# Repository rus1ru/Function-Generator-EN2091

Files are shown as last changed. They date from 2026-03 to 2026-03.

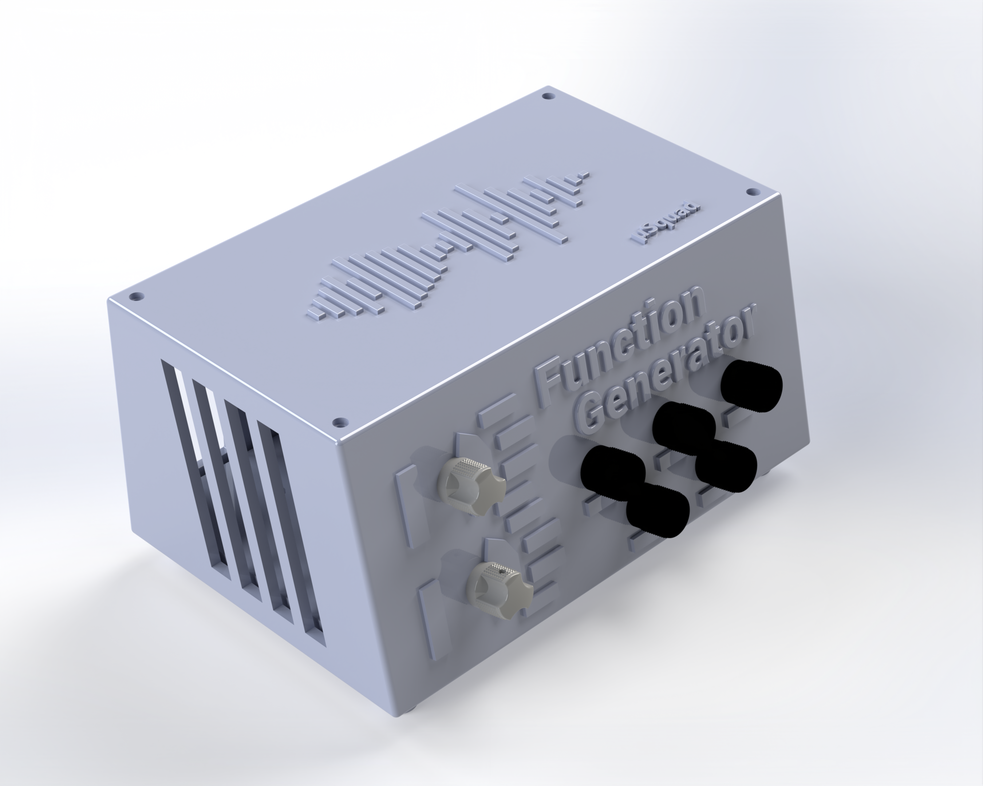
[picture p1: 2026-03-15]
CAD_Files/Vizualize files/isometric view.png

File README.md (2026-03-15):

# Function Generator (EN2091)

Hardware design repository for an analog function generator project, including PCB design sources, mechanical enclosure files, and project documentation.

## Project Overview

This repository contains the design artifacts for the EN2091 Function Generator project:

- Electronic design files (schematic and PCB layout)
- Mechanical enclosure and assembly CAD files
- Exported 3D models for integration and viewing
- Supporting documentation (datasheet, user manual, presentation)

Notes:
- The folder name Enclosuer Design Files is kept as-is to match the existing project structure.
- File naming is preserved from original design exports.

## Design Assets

### 1) PCB Design

Located in PCB Files:

- schematic_Func_Gen.SchDoc: Altium schematic source
- PCB_Func_Gen.PcbDoc: Altium PCB layout source

Use these files for circuit review, design updates, ERC/DRC checks, and fabrication export generation (Gerbers, drill files, BOM, pick-and-place).

### 2) Mechanical and Enclosure Design

Located in Enclosuer Design Files:

- Assembly New.SLDASM: Main SolidWorks assembly
- Box new.SLDPRT: Enclosure body part
- Box New Lid.SLDPRT: Enclosure lid part
- pcba.step: STEP export of the board assembly for mechanical fit checks
- knobs-15.snapshot.5/*.step: Knob variants as STEP files for integration

Use these files for enclosure modification, tolerance/fit validation, and 3D visualization.

### 3) Documentation

- Analog Function Generator Datasheet.pdf
- Analog Function Generator User Manual.pdf
- Analog Function Generator Presentation.pdf

These documents describe project intent, operation, and presentation material.

## Recommended Software

To work with the source files:

- Altium Designer (for .SchDoc and .PcbDoc)
- SolidWorks (for .SLDASM and .SLDPRT)
- Any CAD viewer with STEP support (for .step)
- PDF reader (for project documents)

## Getting Started

1. Clone the repository.
2. Open PCB Files/schematic_Func_Gen.SchDoc and PCB Files/PCB_Func_Gen.PcbDoc in Altium Designer.
3. Open Enclosuer Design Files/Assembly New.SLDASM in SolidWorks.
4. Verify PCB-to-enclosure fit using Enclosuer Design Files/pcba.step.
5. Review the Datasheet and User Manual before making design changes.

## License

This project is licensed under the MIT License.
See the LICENSE file for details.

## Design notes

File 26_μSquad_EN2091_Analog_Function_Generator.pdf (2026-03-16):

## University of Moratuwa

Faculty of Engineering

Department of Electronic and Telecommunication Engineering

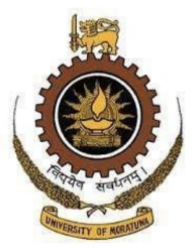
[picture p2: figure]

EN2091 – Laboratory Practice and Projects

Final Report

## Analog Function Generator

Group Members

230436X Nettikumara N.A.H.G. 230436E Rasanjana W.P.G.R.A 230180F Fernando H.M.D.
230322U Karunarathne G.K.T.

Date: 14.12.2025

Abstract

This report presents the design and implementation of an analog function generator capable of producing sine, square, triangular, and sawtooth waveforms. The system was constructed entirely using analog components such as operational amplifiers, transistors, resistors, capacitors, and MOSFETs. The function generator provides adjustable amplitude from 0 V to 10 V, frequency variation from 20 Hz to 20 kHz, and a variable duty cycle for PWM signals ranging from 1% to 99%. Design methodologies, circuit calculations, component selection, PCB layout, enclosure design, and experimental validation are discussed in detail. Simulation and hardware testing confirm that the generator meets the required specifications while maintaining signal integrity.

## Contents

1 Introduction and Functionality | 1
2 Requirements | 1
3 Calculations and Design | 2
4 Selection of Components | 6
5 Power Supply | 6
6 Push-Pull Output with Voltage Buffer, DC shifter and inverting amplifier | 7
7 Simulation and Testing | 8
8 PCB Design | 9
9 Enclosure Design | 11

10 Final Product Results | 13
11 Future Improvements | 14
12 Contribution of Group Members | 14
13 References | 15

## 1 Introduction and Functionality

A function generator is a fundamental laboratory instrument used for testing, debugging, and characterizing electronic systems. It provides periodic waveforms of selectable shape, frequency, and amplitude. In this project, an analog function generator was designed using discrete and integrated analog components, without employing any digital signal generation techniques.

The proposed system is capable of generating square, triangular, sawtooth, and PWM waveforms using a closed-loop configuration consisting of a Schmitt trigger and an integrator. The Schmitt trigger generates a square wave, which is subsequently integrated to obtain triangular and sawtooth waveforms. PWM generation is achieved by appropriate adjustment of the comparator thresholds within the same loop.

For sine wave generation, a Wien bridge oscillator topology was employed due to its low distortion and stable frequency characteristics. All signal-generation and conditioning stages were implemented using TL072CP operational amplifiers, selected for their high slew rate and sufficient bandwidth to support operation across the full frequency range.

The function generator operates over a frequency range of 20 Hz to 20 kHz. Frequency control is achieved using RC-based timing networks, where different frequency bands are selected by switching timing capacitors, and continuous frequency variation within each band is provided by a potentiometer. Amplitude variation and DC offset control are implemented using summing and buffer amplifier stages, enabling flexible output conditioning.

A push-pull output stage ensures sufficient current-drive capability for low-impedance loads. In addition, a dedicated dual-polarity power supply (±12 V) was designed and implemented to meet the operational requirements of the analog circuitry and to ensure stable, symmetric signal swing.

## 2 Requirements

The design meets the following specifications:

- Output waveforms: Sine, Square, Triangle, Sawtooth
- Frequency range: 20 Hz to 20 kHz
- Amplitude variation: 0 V to 10 V
- PWM duty cycle range: 1% to 99%
- Minimum load driving capability: 50 Ω

## 3 Calculations and Design

### 3.1 Square Wave Generation

A Schmitt trigger configuration using an operational amplifier was employed for square wave generation. Positive feedback introduces hysteresis, allowing the circuit to switch states when the input crosses defined threshold levels.

VT H = ±

R8
R8 + R9
Vsat | (1)

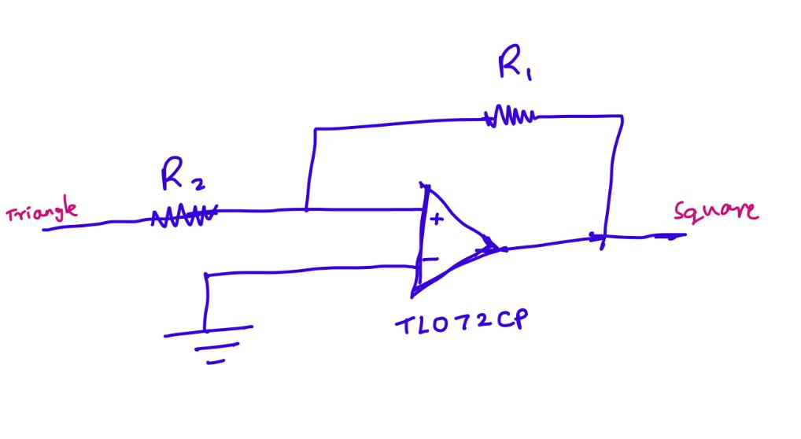
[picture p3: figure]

Figure 1: Schmitt trigger based square wave generator

### 3.2 PWM Wave Generation

Pulse Width Modulation (PWM) is obtained by applying a controllable DC bias to the non-inverting terminal of the integrator. The bias voltage is varied between −Vs (−12 V) and +Vs (+12 V) using the potentiometer R11 connected across the dual supply rails.

A triangular waveform, generated by integrating the square wave output of the Schmitt trigger, is compared against this adjustable reference level. Varying the DC offset shifts the triangular waveform relative to the switching thresholds, thereby altering the switching instants of the output. This results in a PWM waveform whose duty cycle varies continuously while maintaining a constant frequency. Consequently, the average output voltage of the PWM signal can be precisely controlled.

### 3.3 Sawtooth Wave Generation

The sawtooth waveform is generated by introducing a DC offset to the integrator using the potentiometer R11. The applied DC bias causes the charging and discharging slopes of the integrator capacitor to become unequal.

As a result, the capacitor charges slowly in one direction and discharges more rapidly in the opposite direction, transforming the symmetrical triangular waveform into a sawtooth waveform. The degree of asymmetry, and hence the shape of the sawtooth waveform, can be continuously controlled by varying the DC offset voltage.

### 3.4 Triangle Wave Generation

The triangular waveform is obtained by integrating the square wave output of a Schmitt trigger using an op-amp integrator. The Schmitt trigger alternates between positive and negative saturation levels, causing the integrator capacitor to charge and discharge linearly in opposite directions.

This repeated linear integration produces a symmetrical triangular waveform. The output of the integrator is governed by:

Vout(t) = −

1

RC Z
Vin(t) dt | (2)

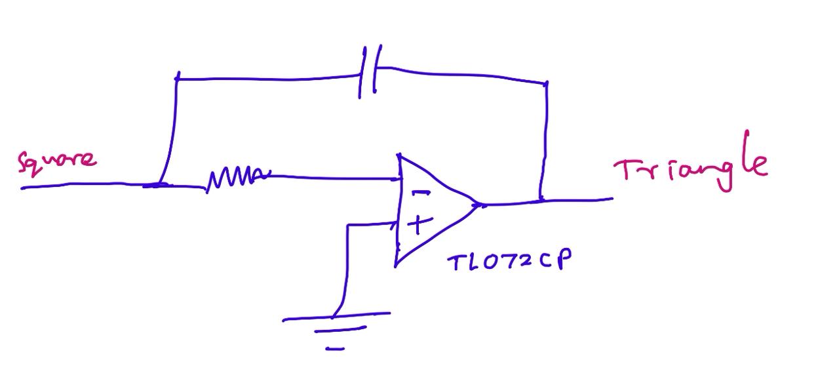
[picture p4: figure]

Figure 2: Integrator based triangle wave generator

The frequency of the triangular waveform is determined by the resistor and capacitor values of the integrator and the hysteresis characteristics of the Schmitt trigger. Frequency variation is achieved by switching timing capacitors and adjusting the associated resistance, allowing operation over the desired frequency range.

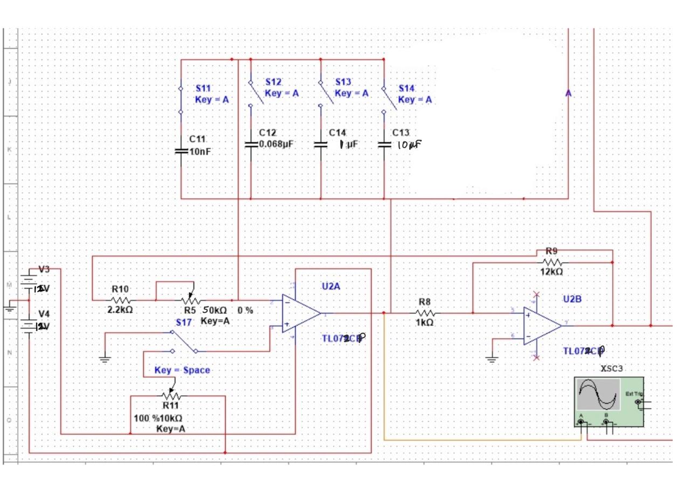
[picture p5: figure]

Figure 3: Square and triangle wave generator

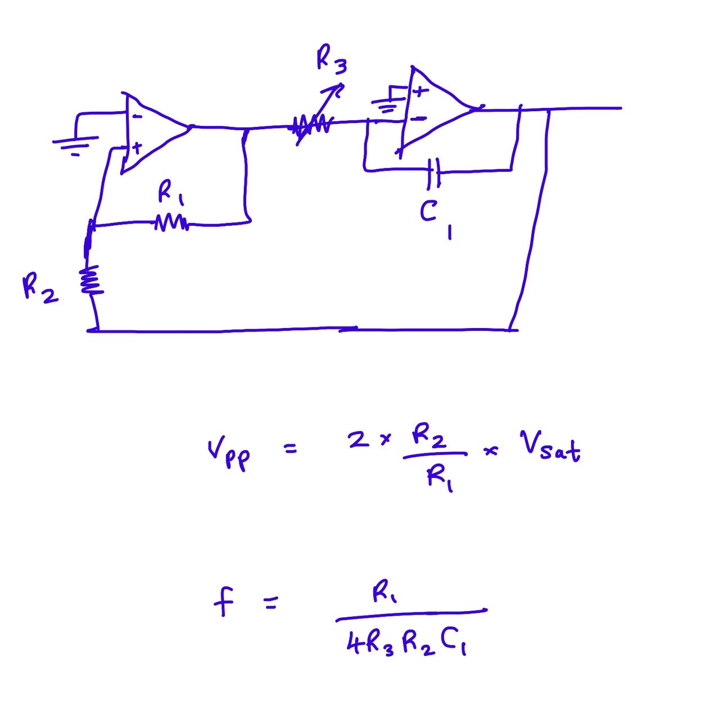
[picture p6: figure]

Figure 4: Resulting Frequency

### 3.5 Frequency Variation for Square and Triangle Wave Generation

Frequency variation for square and triangular wave generation is achieved using a capacitor bank connected to the integrator circuit. Different capacitors are selected using a switch to define distinct frequency regions, while a potentiometer provides fine frequency adjustment within each selected range.

The use of multiple timing capacitors allows the function generator to cover a wide frequency span while maintaining stability and linearity of the generated waveforms.

Frequency Range | Capacitor Value
20 Hz – 130 Hz | 10 µF
130 Hz – 1.5 kHz | 1 µF
1.5 kHz – 15.6 kHz | 68 nF
15.6 kHz – 20 kHz | 10 nF

Table 1: Capacitor selection for square and triangle wave frequency ranges

### 3.6 Sine Wave Generation Using Wien Bridge Oscillator

The sine wave output is generated using a Wien bridge oscillator configuration due to its low distortion and good frequency stability. The oscillator employs a frequency-selective RC network in the feedback path, which determines the oscillation frequency.

Amplitude stabilization is achieved using the nonlinear characteristics of the feedback network, ensuring sustained oscillations without excessive distortion. The TL072CP operational amplifier is used in this stage because of its high slew rate and sufficient bandwidth for audiofrequency operation.

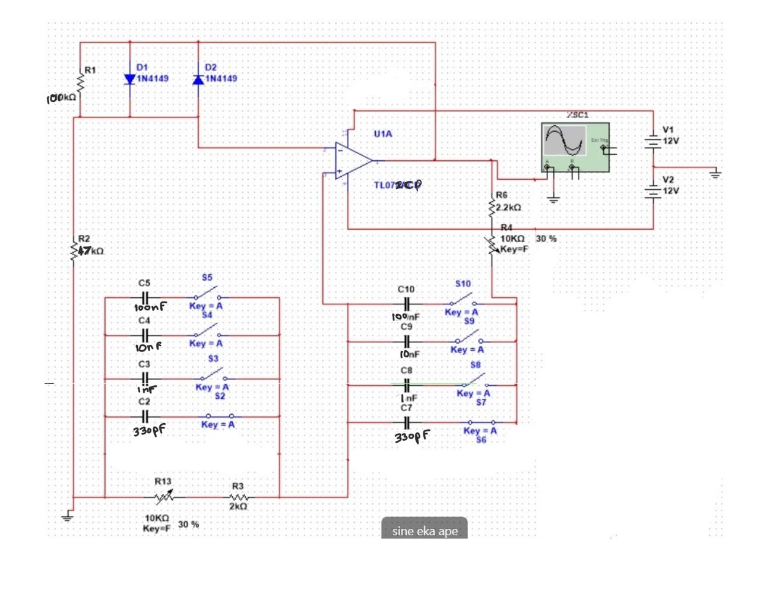
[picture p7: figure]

Figure 5: Vienn bridge Oscillator based sine wave generator

### 3.7 Frequency Variation for Sine Wave Generation

The frequency of the Wien bridge oscillator is controlled by selecting different capacitor values in the RC feedback network. A potentiometer is used in conjunction with these capacitors to allow continuous frequency variation within each range.

This method enables the sine wave generator to operate across the full audio frequency band while maintaining waveform purity.

Frequency Range | Capacitor Value
20 Hz – 690 Hz | 100 nF
690 Hz – 5.5 kHz | 10 nF
5.5 kHz – 12 kHz | 1 nF
12 kHz – 20 kHz | 330 pF

Table 2: Capacitor selection for sine wave frequency ranges

## 4 Selection of Components

### 4.1 Operational Amplifier Selection

The TLO72CP operational amplifier was selected due to its high slew rate of 14 V/µs and gain bandwidth product of 3 MHz, ensuring minimal distortion at higher frequencies.

### 4.2 Transistor Selection

2N2222 (NPN) and 2N3906 (PNP) transistors were used in the push-pull output stage to provide balanced current amplification.

## 5 Power Supply

A dual ±12 V power supply was designed using linear voltage regulators to meet the operational requirements of the analog circuitry.

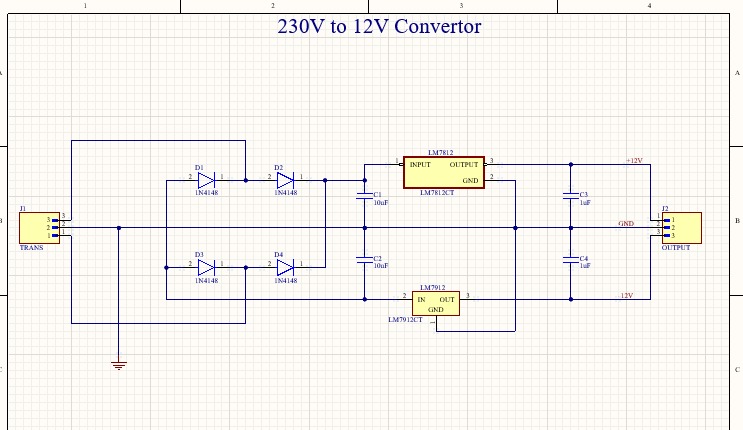
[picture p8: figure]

Figure 6: Dual power supply circuit

## 6 Push-Pull Output with Voltage Buffer, DC shifter and inverting amplifier

The output stage of the function generator consists of a DC offset control stage, a variable gain amplifier, a unity gain voltage buffer, and a push-pull output amplifier to ensure proper signal conditioning and sufficient current drive capability.

A controllable DC shift is introduced using the potentiometer R15, which is connected between the dual supply rails of +12 V and −12 V. By adjusting R15, the reference voltage applied to the non-inverting input of the first operational amplifier is varied, allowing the output waveform to be shifted vertically without altering its shape.

The amplitude of the output signal is controlled using the potentiometer R16 in the feedback path of the operational amplifier. This configuration provides continuous gain adjustment while maintaining linear amplification of the input waveform.

The conditioned signal is then fed into a second operational amplifier configured as a unity gain voltage buffer. This buffer provides high input impedance and low output impedance, effectively isolating the signal-conditioning circuitry from the load and preventing loading effects.

Finally, a complementary push-pull emitter follower stage implemented using NPN and PNP transistors is employed to enhance the current-driving capability of the function generator. This stage allows the circuit to drive low-impedance loads while preserving waveform integrity and minimizing distortion at the output.

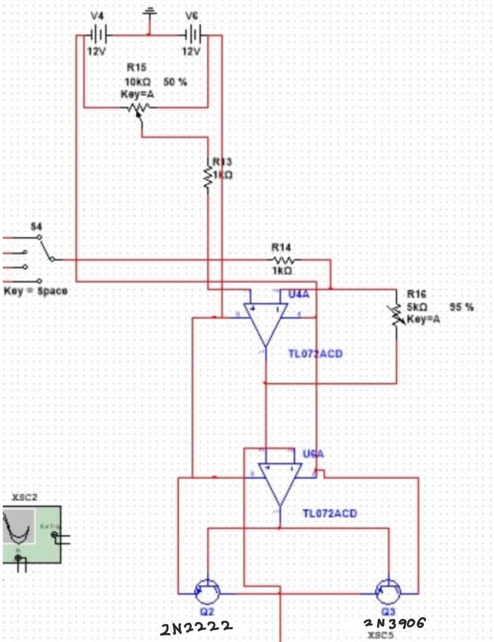
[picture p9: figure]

Figure 7: Output circuit

## 7 Simulation and Testing

### 7.1 Simulation

The complete circuit was simulated using NI Multisim. Frequency response, waveform integrity, and duty cycle variation were verified prior to hardware implementation.

### 7.2 Hardware Testing

The prototype was tested using an oscilloscope and resistive loads. Generated waveforms closely matched simulation results across the specified frequency and amplitude ranges.

## 8 PCB Design

A double-layer PCB was designed using Altium Designer, with careful grounding and signal routing to minimize noise.

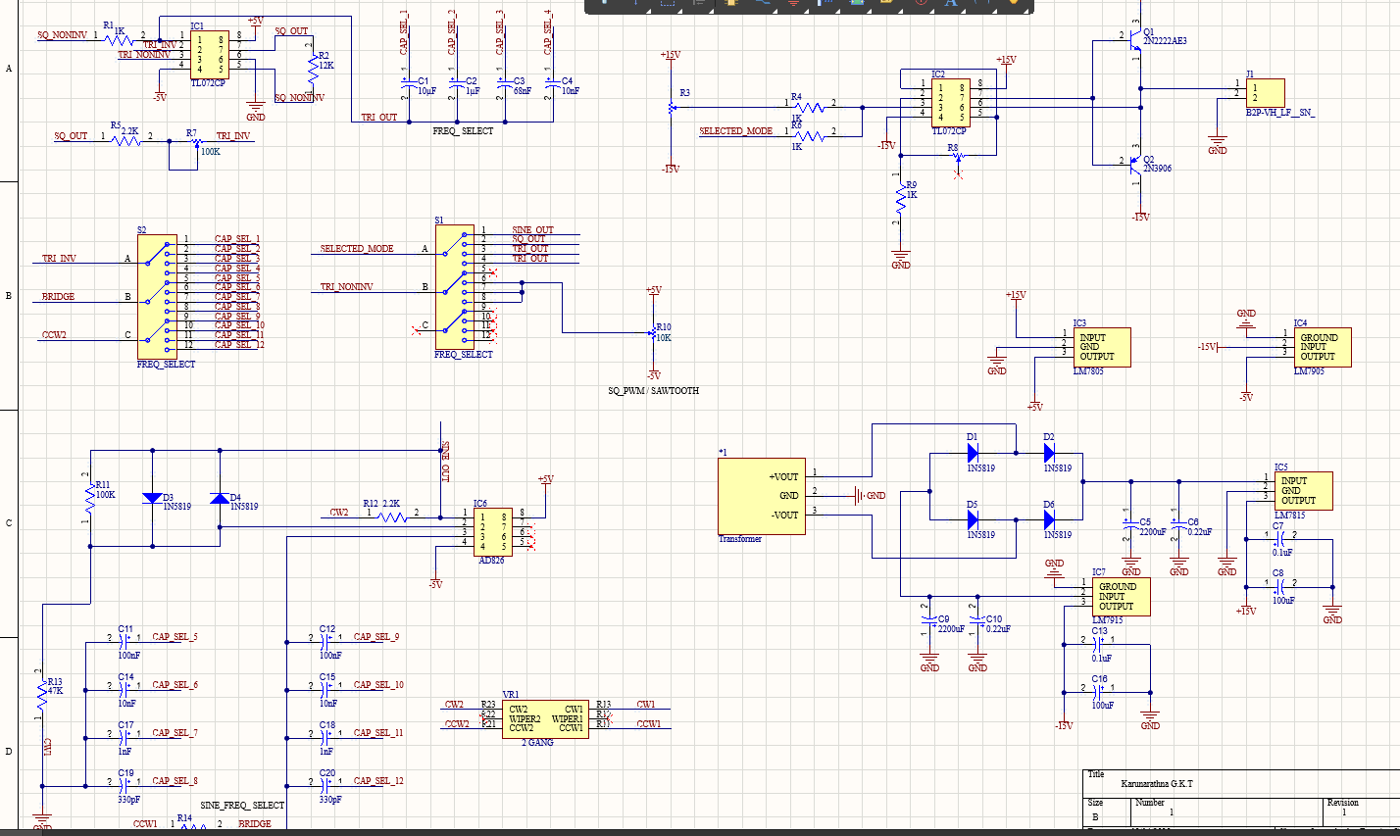
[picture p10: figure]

Figure 8: Schematic

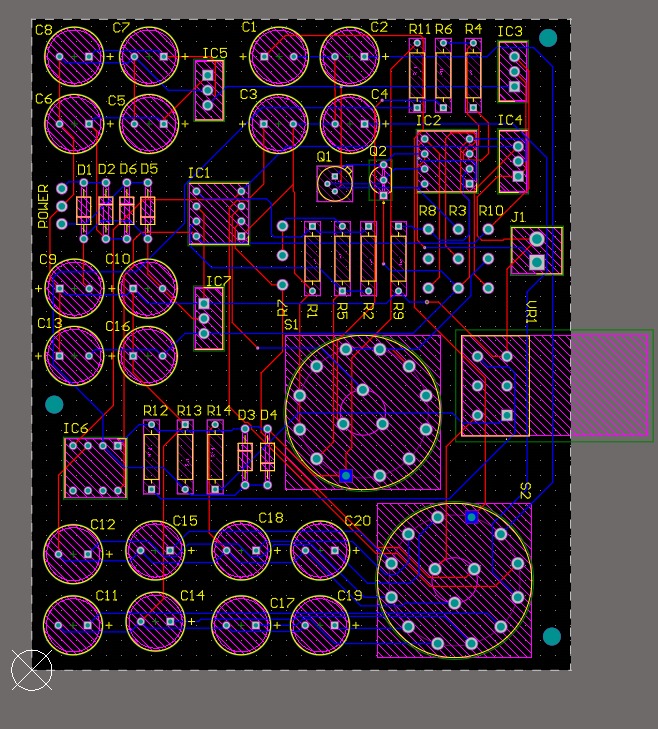
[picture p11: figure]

Figure 9: PCB

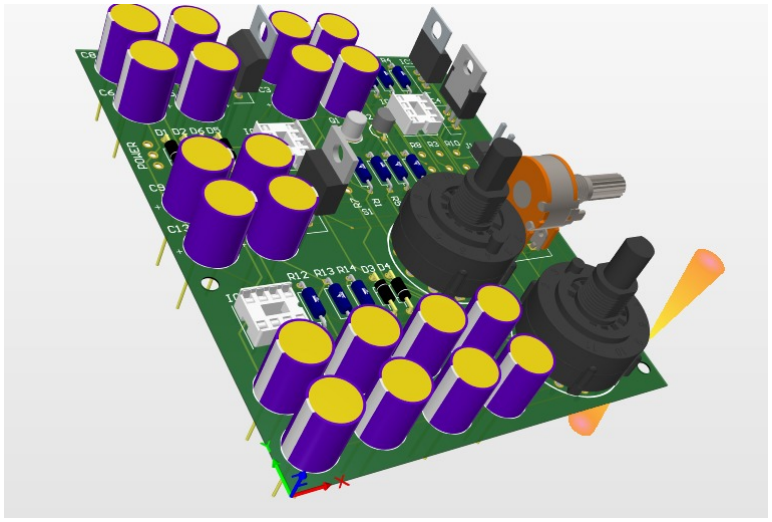
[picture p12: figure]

Figure 10: 3-D view

## 9 Enclosure Design

The enclosure was modeled using SolidWorks and fabricated to provide mechanical protection and user accessibility.

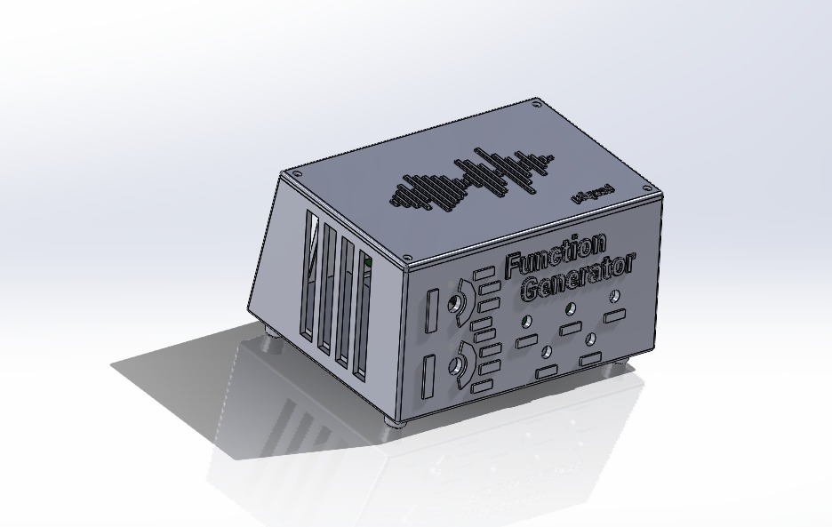
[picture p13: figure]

Figure 11: Enclosure

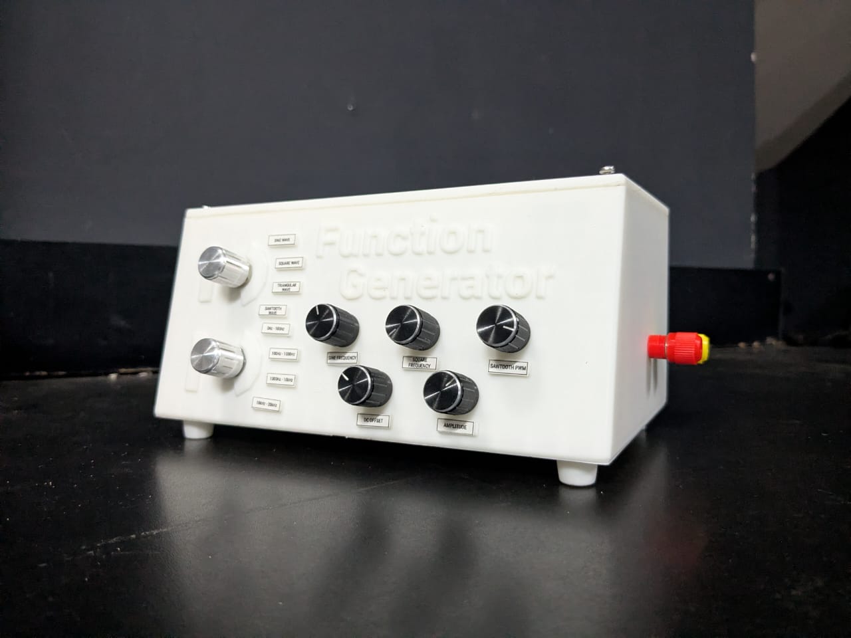
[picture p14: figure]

Figure 12: Physical Enclosure

## 10 Final Product Results

The following oscilloscope captures show the output waveforms obtained from the implemented analog function generator, demonstrating correct operation across different waveform modes and frequency ranges.

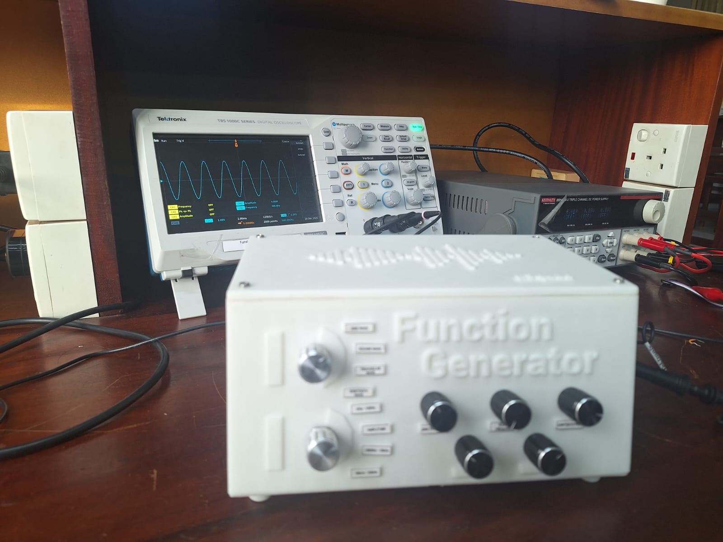
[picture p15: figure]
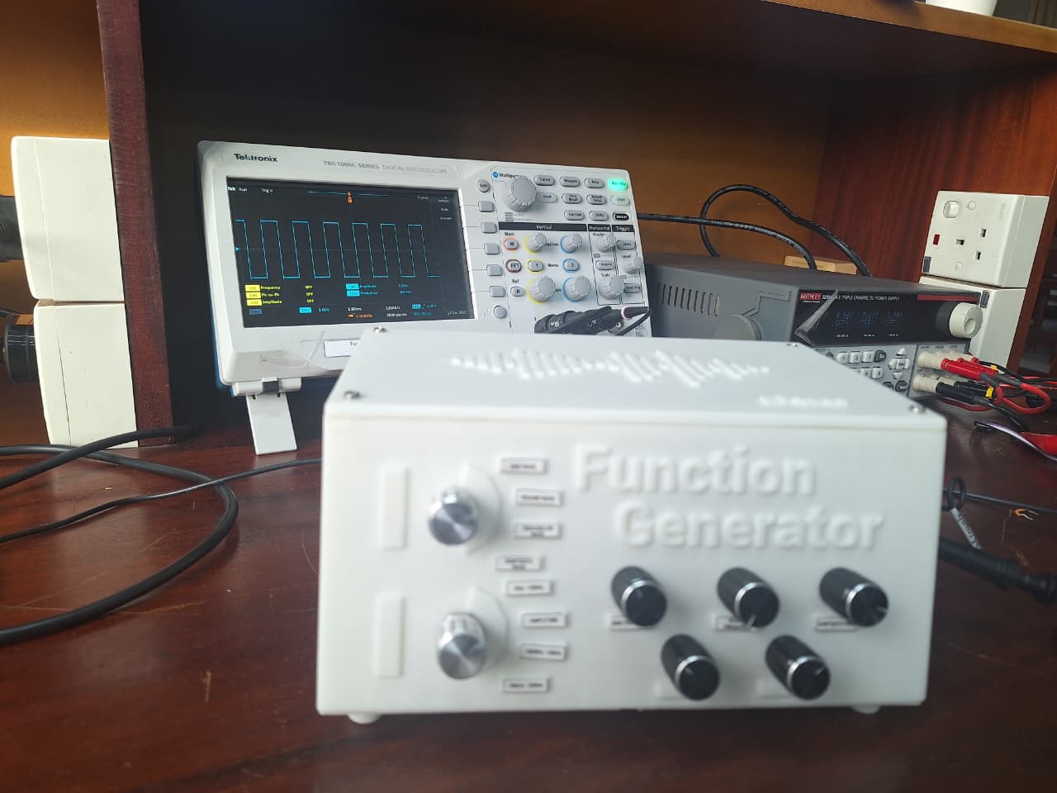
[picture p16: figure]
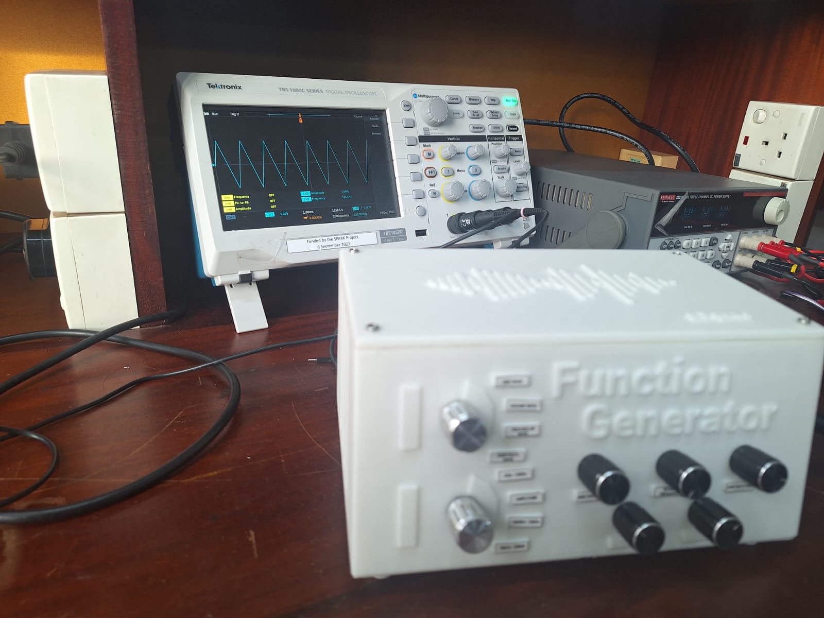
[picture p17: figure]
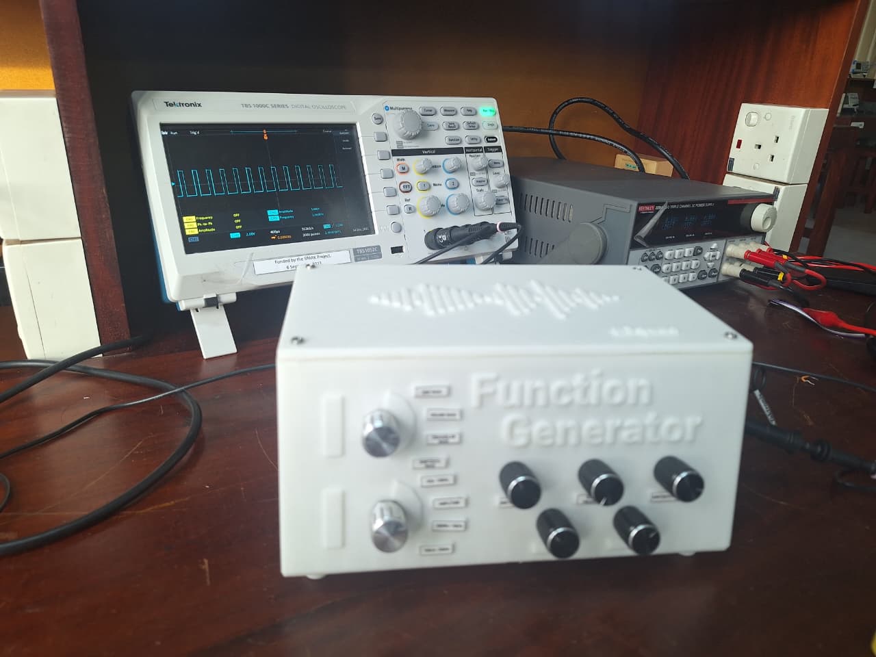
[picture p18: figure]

Figure 13: Oscilloscope results of the implemented analog function generator

## 11 Future Improvements

Future enhancements include improving sawtooth linearity and implementing higher-order filtering for cleaner sine wave generation.

## 12 Contribution of Group Members

- 230436X: Simulation, Prototyping, Assembly, Documentation
- 230180F: Prototyping, Enclosure Design,Assembly,Documentation
- 230536E: Simulation, Prototyping, Documentation, Assembly
- 230322U: Prototyping, PCB Design, Assembly.

## 13 References

1. Wikipedia, “Function Generator.” Available: https://en.wikipedia.org/wiki/Function_
generator (https://en.wikipedia.org/wiki/Function_generator)
2. All About Circuits, “How to Build Your Own Function Generator Using Analog Devices’
AD9833.” Available: https://www.allaboutcircuits.com/projects/how-to-DIY-waveform-generator-analog-devices-ad9833-ATmega328p/
3. Instructables, “DIY Function / Waveform Generator.” Available: https://www.instructables.
com/DIY-FunctionWaveform-Generator/ (https://www.instructables.com/DIY-FunctionWaveform-Generator/)
4. Learning About Electronics, “How to Build a Simple Function Generator with an LM324
Op Amp Chip.” Available: http://www.learningaboutelectronics.com/Articles/Function-generator-circuit.php (http://www.learningaboutelectronics.com/Articles/Function-generator-circuit.php)
5. Instructables, “Analog Function Generator.” Available: https://www.instructables.com/Function-Generator/ (https://www.instructables.com/Function-Generator/)
6. EEEGuide, “Triangular Wave Generator Using Op Amp.” Available: https://www.eeeguide.com/triangular-wave-generator-using-op-amp/
7. Analog Devices, “Precision Triangular-Wave Generator Uses a Single IC.” Available: https://www.analog.com/en/technical-articles/precision-triangularwave-generator-uses-a-single-ic. html (https://www.analog.com/en/technical-articles/precision-triangularwave-generator-uses-a-single-ic.html)
8. Floyd, T. L., Electronics Fundamentals: Circuits, Devices and Applications. Pearson
Education. Available: https://www.amazon.com/Electronics-Fundamentals-Circuits-Devices-Applications/dp/0135072956 (https://www.amazon.com/Electronics-Fundamentals-Circuits-Devices-Applications/dp/0135072956)

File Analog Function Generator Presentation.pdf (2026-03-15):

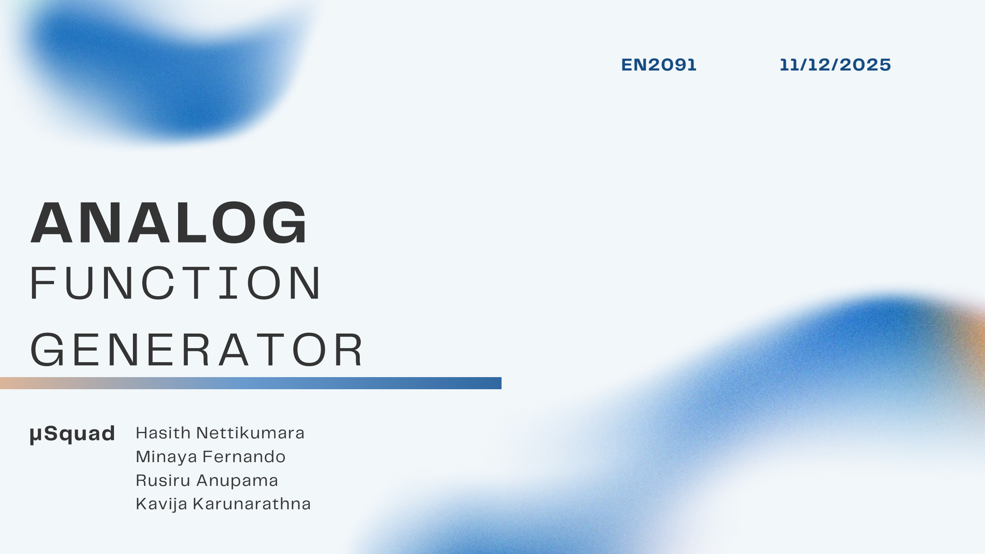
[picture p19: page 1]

# ANALOG

# FUNCTION GENERATOR

## μSquad

EN2091 | 11/12/2025

Hasith Nettikumara
Minaya Fernando
Rusiru Anupama
Kavija Karunarathna

# WHAT DID

# 01 WE BUILD?

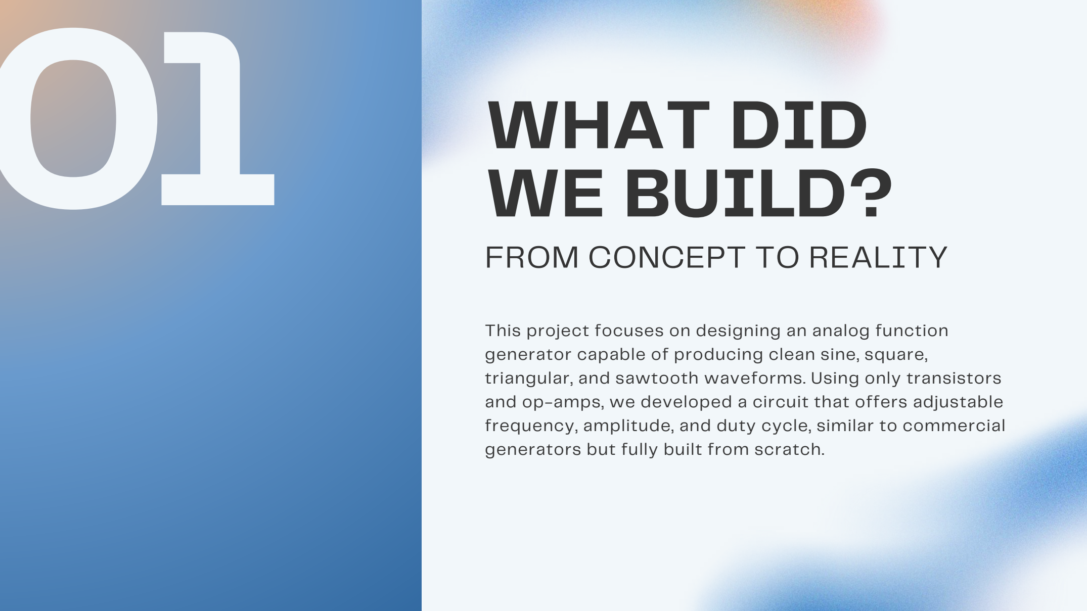
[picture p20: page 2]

# FROM CONCEPT TO REALITY

This project focuses on designing an analog function generator capable of producing clean sine, square, triangular, and sawtooth waveforms. Using only transistors and op-amps, we developed a circuit that offers adjustable frequency, amplitude, and duty cycle, similar to commercial generators but fully built from scratch.

# PRODUCING

THE BIG 3 | 02

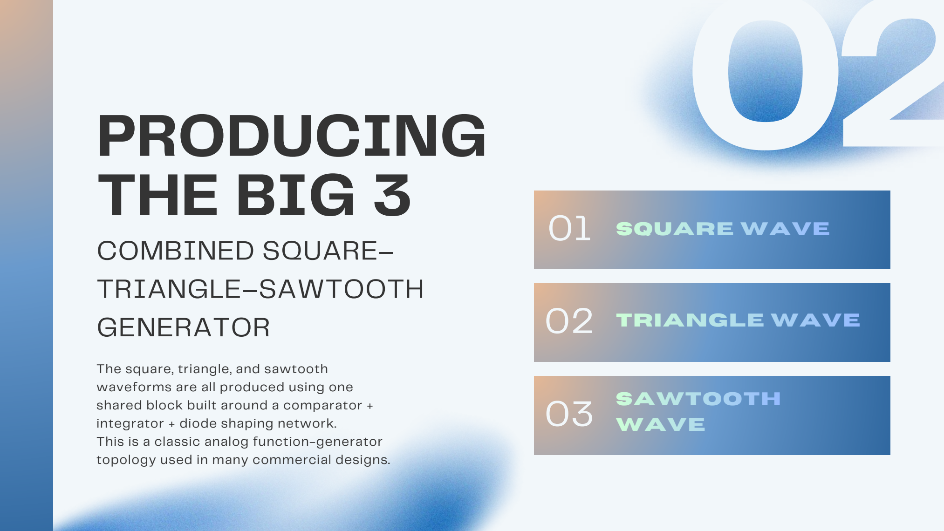
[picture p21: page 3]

# COMBINED SQUARE– TRIANGLE–SAWTOOTH GENERATOR

01

02

The square, triangle, and sawtooth waveforms are all produced using one shared block built around a comparator + integrator + diode shaping network.
This is a classic analog function-generator topology used in many commercial designs.

03

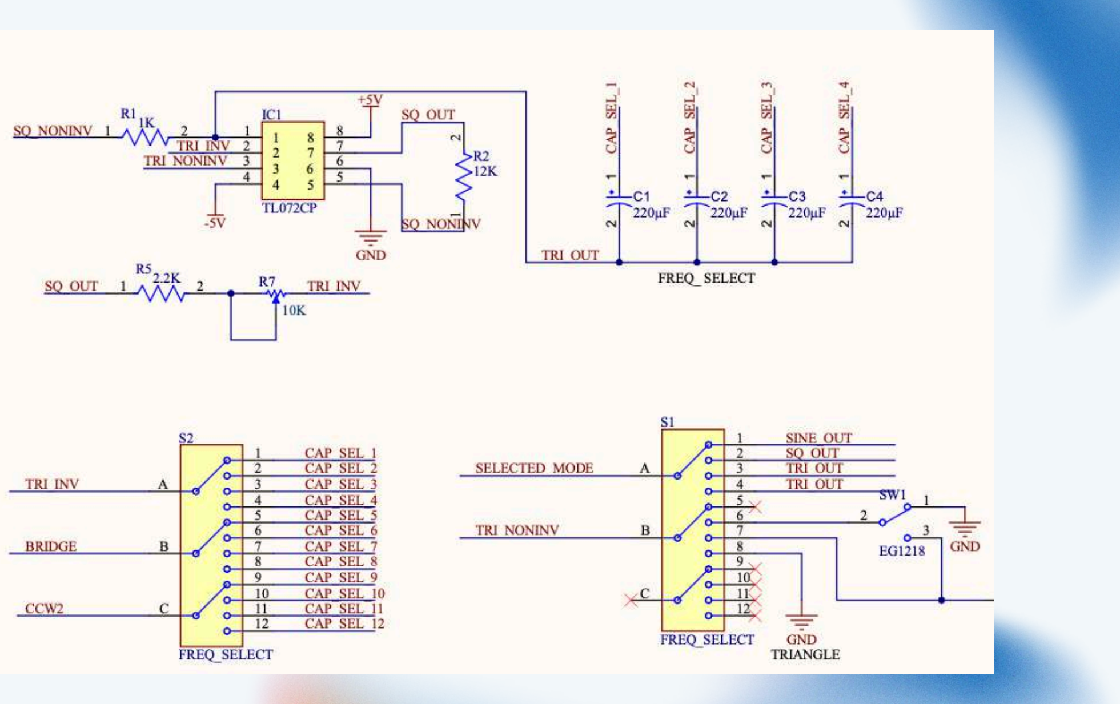
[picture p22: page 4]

04

01 02

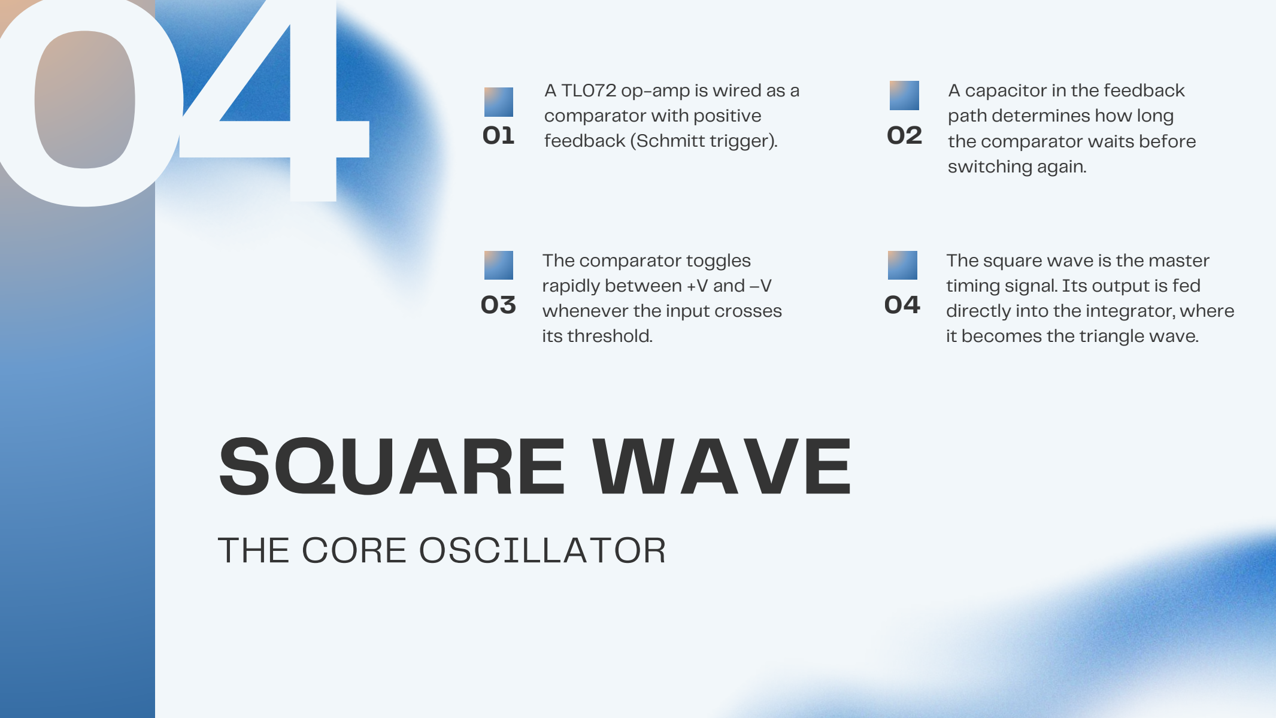
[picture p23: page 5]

# SQUARE WAVE

03 04

# THE CORE OSCILLATOR

The square wave is the master timing signal. Its output is fed directly into the integrator, where it becomes the triangle wave.

The comparator toggles
rapidly between +V and –V
whenever the input crosses its threshold.

A TL072 op-amp is wired as a comparator with positive
feedback (Schmitt trigger).

A capacitor in the feedback path determines how long
the comparator waits before switching again.

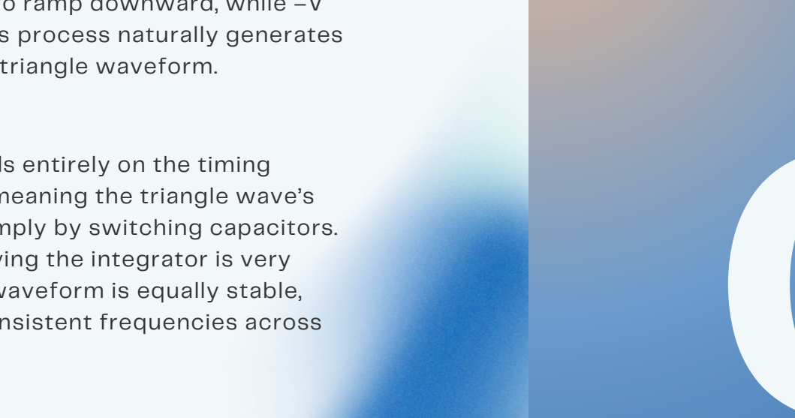
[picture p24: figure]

05

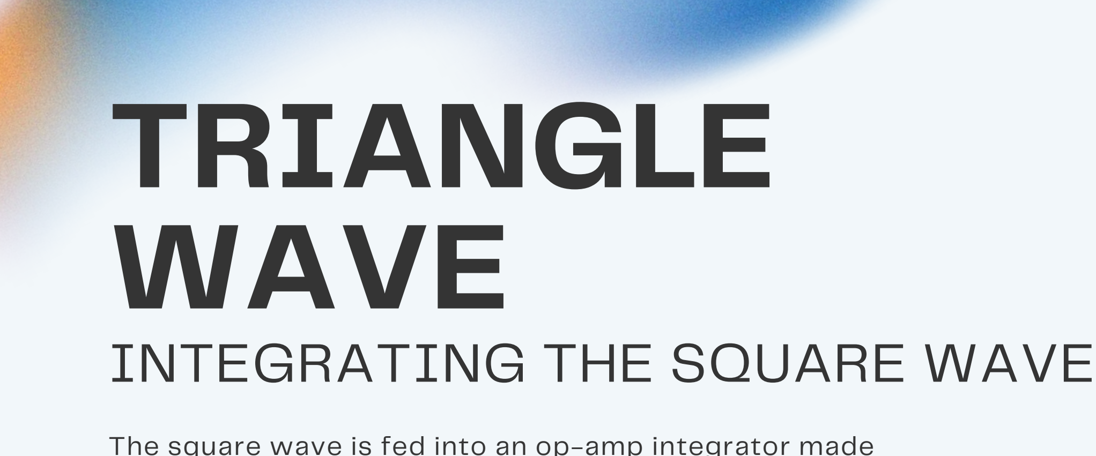
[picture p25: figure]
TRIANGLE WAVE; INTEGRATING THE SQUARE WAVE

The square wave is fed into an op-amp integrator made from a resistor, a timing capacitor, and a stabilizing feedback network. Since a square wave spends equal time at +V and –V, the integrator responds by producing linear ramps: +V causes the output to ramp downward, while –V causes it to ramp upward. This process naturally generates a clean and highly symmetric triangle waveform.

The integrator’s slope depends entirely on the timing capacitor and input resistor, meaning the triangle wave’s frequency can be changed simply by switching capacitors. Because the square wave driving the integrator is very stable, the resulting triangle waveform is equally stable, producing predictable and consistent frequencies across different ranges.

# SAWTOOTH WAVE


06

Sawtooth is created by feeding the integrator a non-50% duty-cycle square wave.
When the square wave stays high longer than low, the integrator ramps slowly in one direction and quickly in the other.
This asymmetric ramping produces the classic sawtooth shape.
Adjusting the duty cycle directly controls the slope ratio of the rise vs. fall.

A D

07

ely; illa; cla; alo; pli; ble; alu; ele

- lag RC network that provides positive feedback only at one specific frequency.

ol in the op-amp stage (preventing clipping or decay).

n lab-grade function generators due to its low distortion and excellent stability.

# POWER SUPPLY


08

The circuit uses a dual-rail power supply to support both analog and output-drive stages.
Voltage regulators 7815, 7915, 7805, and 7905 provide stable ±15 V and ±5 V rails.
The ±15 V rails power the op-amps that generate and shape the waveforms.
The ±5 V rails are used for biasing, reference levels, and low-voltage stages.
Filtering capacitors smooth out the regulator outputs, reducing ripple and noise.
This ensures the oscillators and integrators operate with clean, stable supply voltages, improving waveform quality and reducing distortion.


0

9


# PRINTED CIRCUIT

# BOARD

109


# ENCLOSURE

# DESIGN

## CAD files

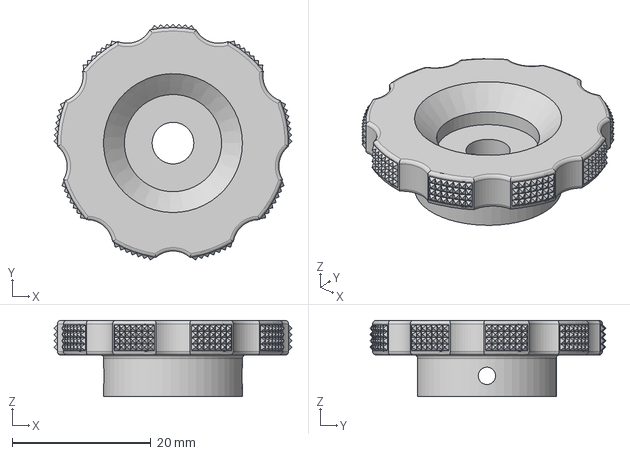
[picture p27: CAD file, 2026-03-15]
CAD_Files/Downloads/knobs-15.snapshot.5/knobbi4.step
34.3 x 34.0 x 11.0 mm

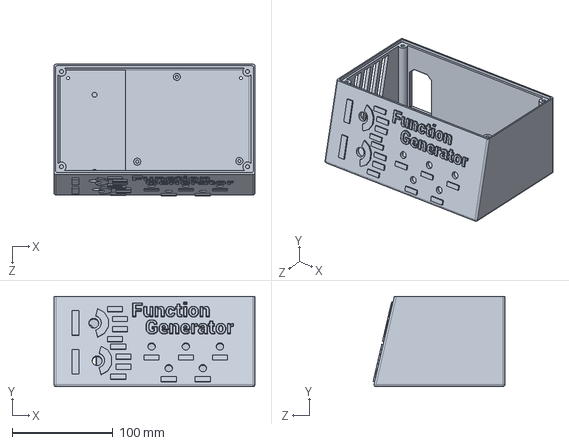
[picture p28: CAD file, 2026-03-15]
CAD_Files/Parts/Box new.SLDPRT
200.0 x 90.0 x 131.1 mm

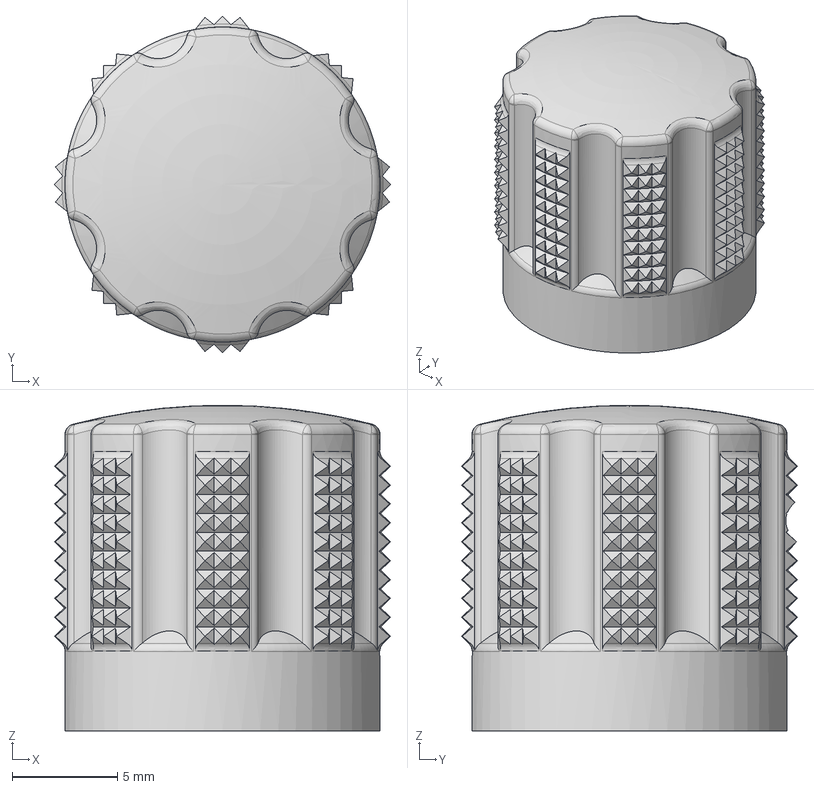
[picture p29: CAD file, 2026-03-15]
CAD_Files/Downloads/knobs-15.snapshot.5/knobbi3.step
16.0 x 16.0 x 15.5 mm

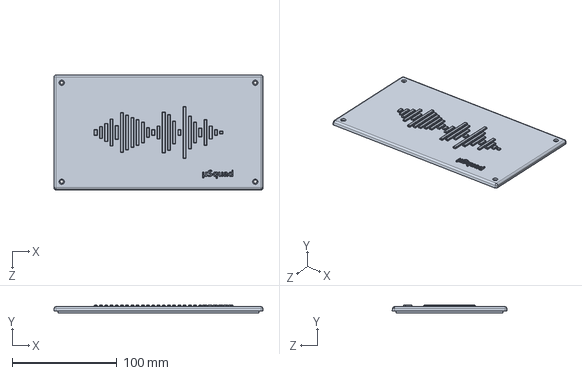
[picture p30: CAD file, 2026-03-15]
CAD_Files/Parts/Box New Lid.SLDPRT
200.0 x 7.50 x 110.0 mm

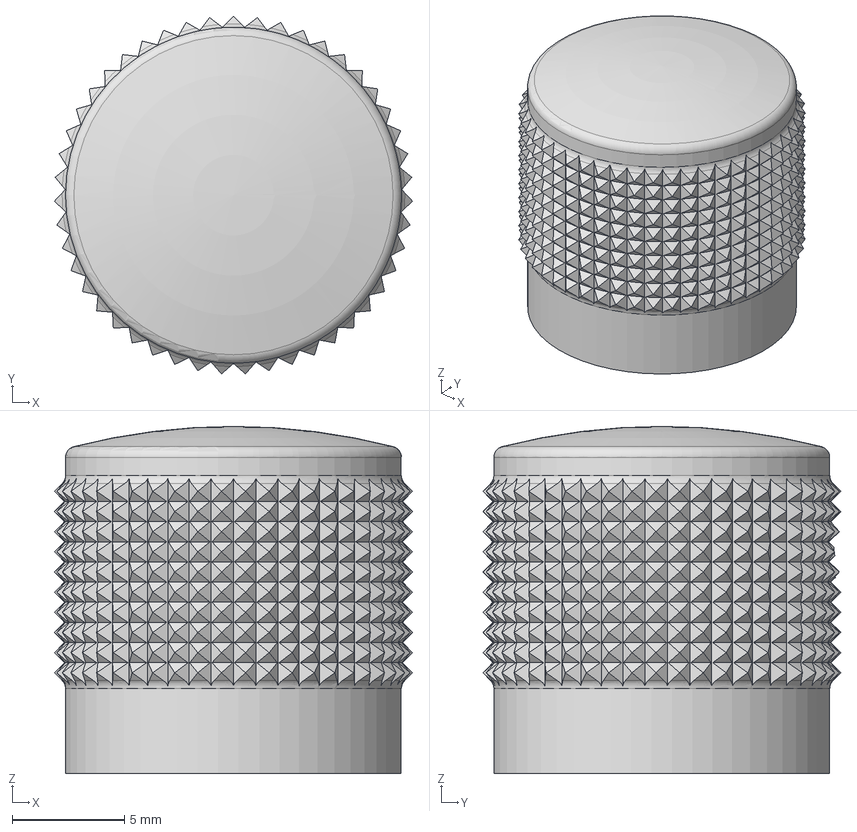
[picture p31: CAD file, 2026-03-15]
CAD_Files/Downloads/knobs-15.snapshot.5/knobbi2.step
16.0 x 16.0 x 15.5 mm

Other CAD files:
CAD_Files/Downloads/knobs-15.snapshot.5/knobbi1.step

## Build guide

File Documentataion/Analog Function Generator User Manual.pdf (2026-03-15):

# U S E R M A N U A L

# μSquad

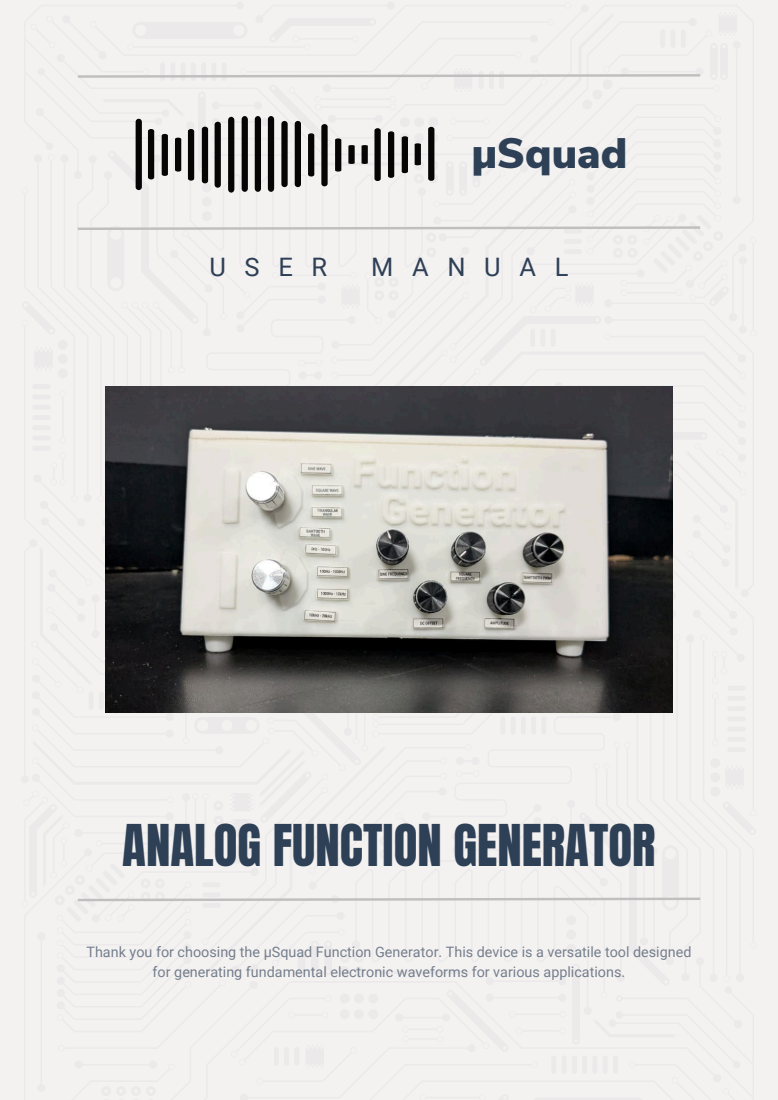
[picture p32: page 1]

ANALOG FUNCTION GENERATOR

Thank you for choosing the μSquad Function Generator. This device is a versatile tool designed

for generating fundamental electronic waveforms for various applications.

# μSquad

# 1. INTRODUCTION

To generate essential waveforms: sine, square, triangular, and sawtooth.

It is an Analogue Function Generator with a robust, self-contained power supply.

All four waveforms feature adjustable parameters for Frequency, Amplitude, and DC Offset Voltage.

The duty cycle can be precisely adjusted when generating a square wave.

### Primary Fuction

### Design

### Key Parameters

### Special Feature

# 2. SAFETY INFORMATION

The device accepts standard AC wall power and converts it internally. Do not attempt to apply DC power directly. The internal circuitry operates using a +/- 12V dual-supply, and the final signal output range is from +12V to -12V.

Do not expose the device to moisture, rain, or liquids. Avoid placing it near heat sources (amplifiers, radiators, sunlight).

Ensure ventilation grills remain unobstructed

Disconnect power before servicing.

### Power Supply

### Environment

### Ventilation:

### Servicing

# 3. INSTALLATION & SETUP

Connect a standard AC power cord into the power socket on the device. Then, plug the cord into a standard wall outlet. The device's internal circuitry safely handles the conversion from the AC wall power to the necessary +/- 12V DC supply.

### Connect AC Power Input

STEP 01

Connect your test equipment (e.g., oscilloscope) using the dedicated signal terminals. Connect the oscilloscope probe's hook clip to the Ground terminal and the probe tip to the Signal Output terminal. The final signal output range is from +12V to -12V.

### Connect Output to Test Equipment

STEP 02

Switch | Name | Function | Detailed Operation
Switch 1 | Waveform Type Selector | Selects the primary waveform type for the output signal. | Turn to the desired position to output Sine, Square, Triangle, or Sawtooth.
Switch 2 | Frequency Range Selector | Selects the coarse frequency range. | Adjust this switch to select the appropriate frequency range before fine-tuning with the knobs. This dictates the range for both Sine and the other waveforms.
Knob | Control Name | Function | Detailed Operation
P1 | Sine Frequency Deviation | Provides fine frequency adjustment for the Sine wave within the range set by Switch 2. | Use this knob to precisely set the Sine wave frequency after selecting the coarse range.
P2 | Square/Triangle Frequency Deviation | Provides fine frequency adjustment for Square, Triangle, and Sawtooth waves within the range set by Switch 2. | This knob works similarly to P1 but affects the other three waveforms.
P3 | PWM / Duty Cycle | Adjusts the Pulse Width Modulation (PWM) or the Duty Cycle of the Square wave. | Rotate to change the symmetry/pulse width of the square wave. (This control is non-functional for Sine and Triangle waves).
P4 | Amplitude | Controls the peak-to-peak voltage of the output signal. | Rotate clockwise to increase the output amplitude. The maximum output is +/- 12V.
P5 | DC Offset | Controls the DC bias applied to the waveform. | Rotate to shift the entire signal waveform above or below $0\text{V}$ (the offset).

# 4. PRODUCT OVERVIEW : FRONT PANEL CONTROLS

### These switches determine the basic shape and the coarse frequency range of

the output signal.

A. WAVEFORM & FREQUENCY SELECTION SWITCHES
B. POTENTIOMETERS (KNOBS)
These five knobs provide fine control over the frequency, shape, amplitude, and DC bias of the signal.

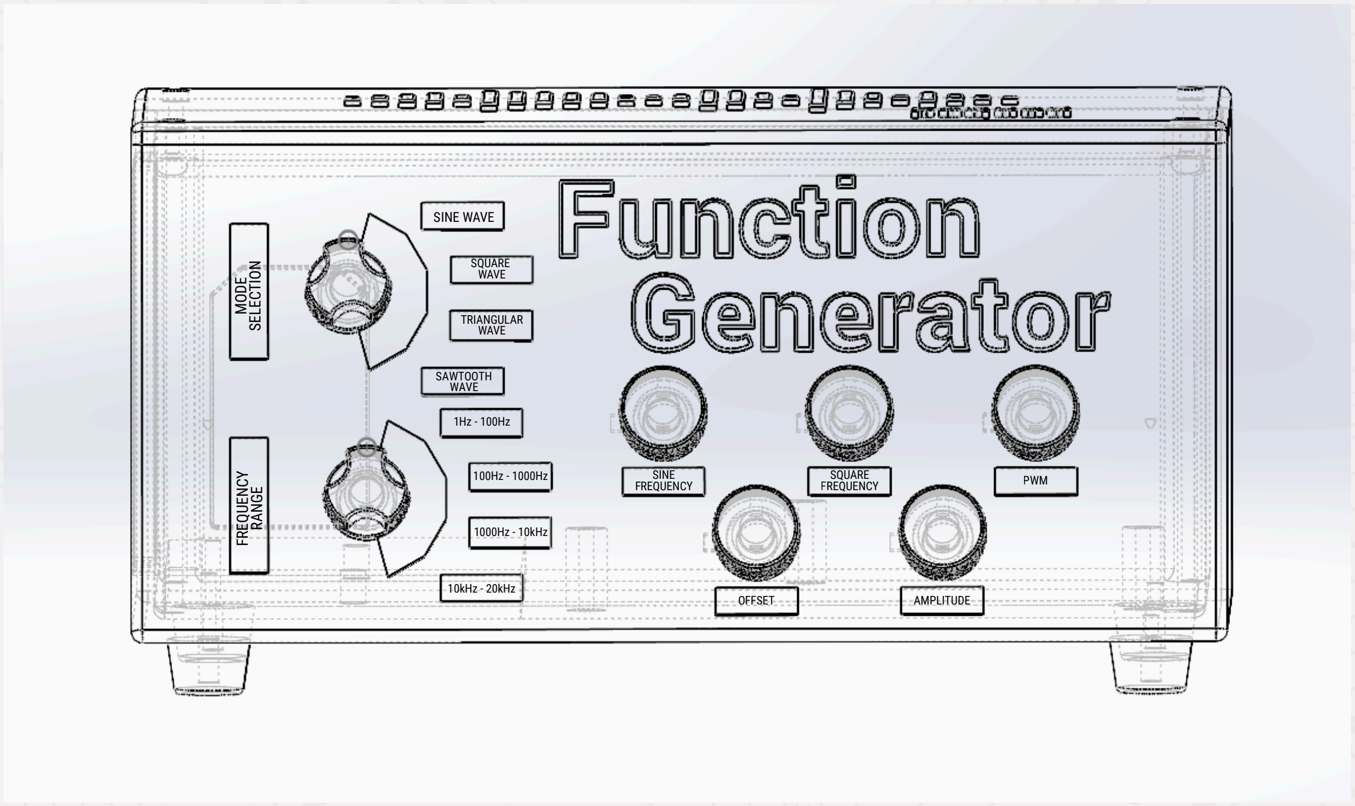
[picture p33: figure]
SINE WAVE SQUARE; WAVE; TRIANGULAR WAVE; SAWTOOTH WAVE; FREQUENCY; SQUARE FREQUENCY

1Hz - 100Hz 100Hz - 1000Hz 1000Hz - 10kHz 10kHz - 20kHz | SINE
PWM OFFSET | AMPLITUDE MODE SELECTION FREQUENCY RANGE Thank you for choosing the μSquad Function Generator. This device is a versatile tool designed

for generating fundamental electronic waveforms for various applications.

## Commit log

2026-03-15 Add new CAD parts for the enclosure
    [Box New Lid.SLDPRT, Box new.SLDPRT, knobbi1.step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]
2026-03-15 Add isometric view PNG for visualization in CAD files
2026-03-15 Added the PCB schematic and layout document
    [PCB_Func_Gen.PcbDoc, schematic_Func_Gen.SchDoc]
